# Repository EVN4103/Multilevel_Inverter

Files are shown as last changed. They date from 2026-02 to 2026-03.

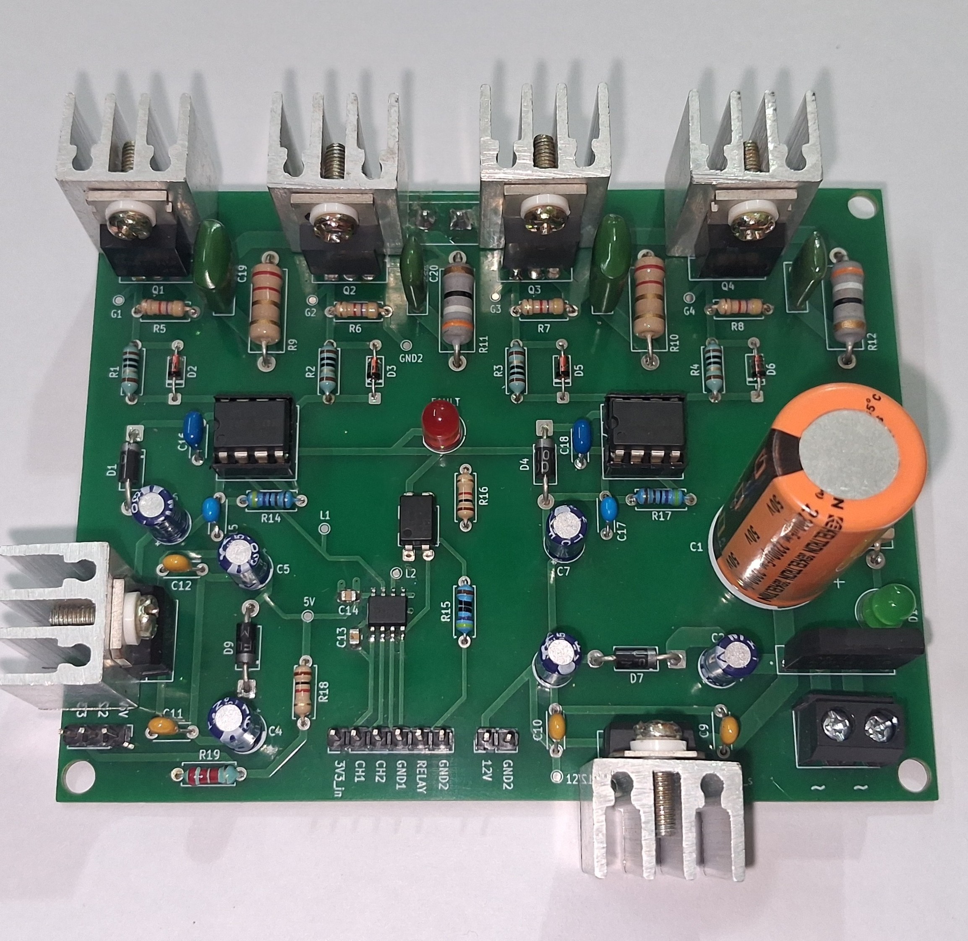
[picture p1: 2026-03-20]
hardware/hardware_setup/h-bridge.jpeg

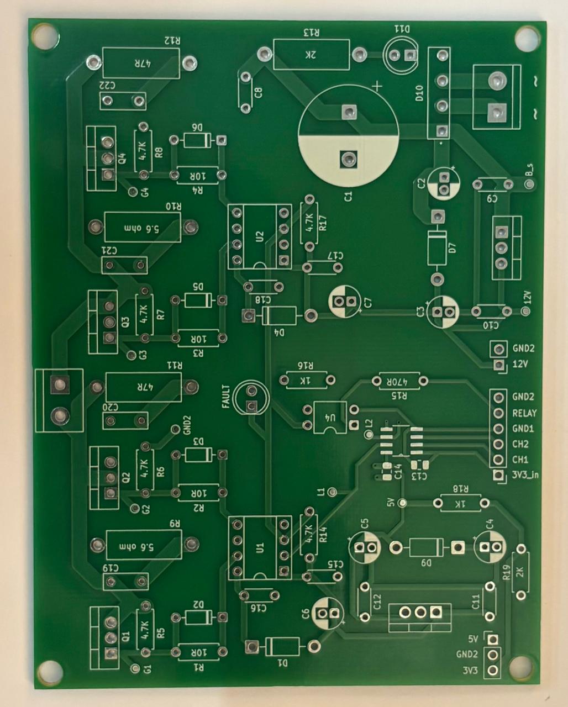
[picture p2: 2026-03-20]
hardware/hardware_setup/fabricated pcb .jpeg

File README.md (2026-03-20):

# 7-Level Cascaded H-Bridge Multilevel Inverter

A 7-Level Cascaded H-Bridge (CHB) Multilevel Inverter designed to generate high-quality AC output using Phase-Shifted Sinusoidal PWM (PS-SPWM) control implemented on an STM32F401 microcontroller.

# Project Overview

This project consists of:

- **Hardware**: Power stage and control PCB designed in KiCad  
- **Firmware**: STM32F401-based inverter control firmware  
- **Control Method**: Phase-Shifted Sinusoidal PWM (PS-SPWM)  
- **Target Applications**: Motor drives, renewable energy systems, medium-voltage inverter systems  

# Hardware

Designed using KiCad (EDA Suite)

# Hardware Features
- 3 Cascaded H-Bridge cells
- 7-level stepped AC output
- Modular and scalable architecture
- Designed for reduced harmonic distortion

# Firmware
Generated using STM32CubeMX  
Developed using STM32CubeIDE  

# Microcontroller
STM32F401CCU6

# Control Strategy
- Phase-Shifted Sinusoidal PWM (PS-SPWM)
- Configurable switching frequency
- Modular control structure

# Key Features

✔ Reduced Total Harmonic Distortion (THD)  
✔ Modular multilevel inverter topology  
✔ Timer-based PWM control  
✔ Scalable to higher voltage levels  
✔ Suitable for renewable and motor drive applications  
✔ Closed-loop voltage control implementation  
✔ FFT-based THD measurement
✔ Over-voltage, under-voltage, and over-current protection

# Prototype Setup
20260317_141503 jpg

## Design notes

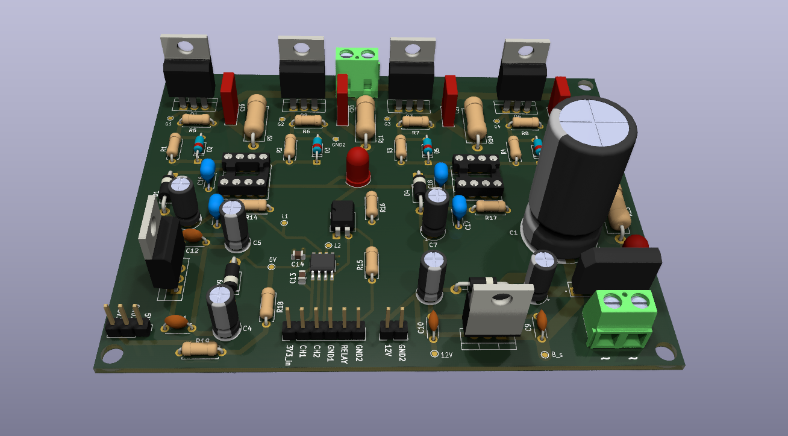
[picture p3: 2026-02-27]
hardware/hardware_design/pcb.png

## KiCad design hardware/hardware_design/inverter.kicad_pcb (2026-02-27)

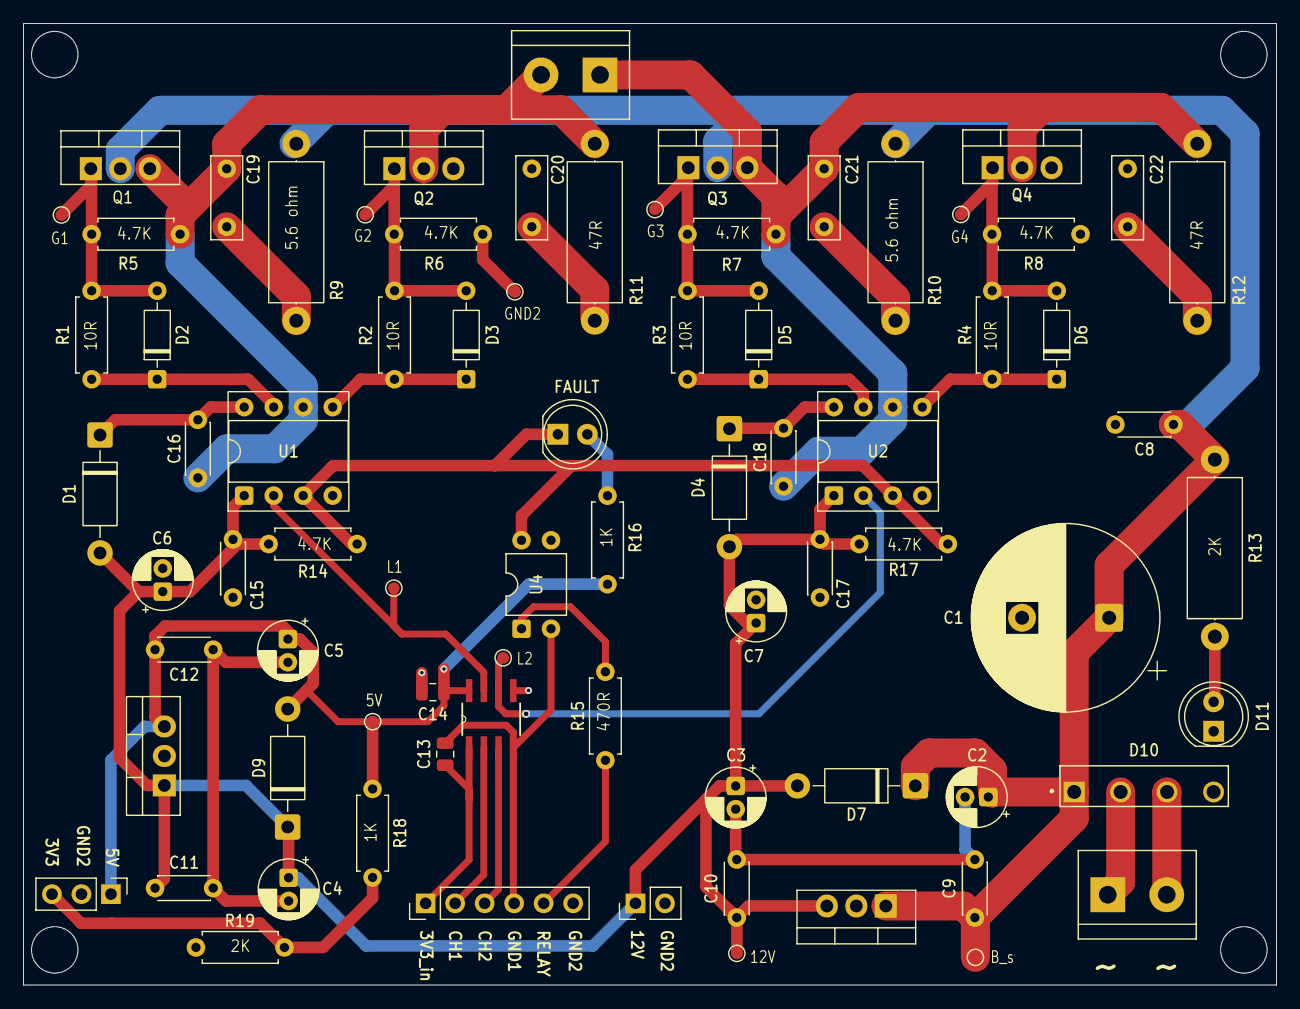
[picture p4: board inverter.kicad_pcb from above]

Board: 2 copper layers, 107.9 x 82.8 mm, 77 parts (0 on the bottom side), 36 nets.

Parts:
C1: 2200uF/50V; CP_Radial_D16.0mm_P7.50mm
C2, C4: 10uf; CP_Radial_D5.0mm_P2.00mm
C3, C5, C6: 10uF; CP_Radial_D5.0mm_P2.00mm
C7: 10uF e; CP_Radial_D5.0mm_P2.00mm
C8: 0.1uf; C_Disc_D4.3mm_W1.9mm_P5.00mm
C9, C11: 0.22uF; C_Disc_D4.3mm_W1.9mm_P5.00mm
C10, C12: 0.1uF; C_Disc_D4.3mm_W1.9mm_P5.00mm
C13, C14: 0.1uf; C_0805_2012Metric
C15, C17: 0.1uF,X7R; C_Disc_D4.3mm_W1.9mm_P5.00mm
C16, C18: 50V 1uF X7R; C_Disc_D4.3mm_W1.9mm_P5.00mm
C19, C21: 10nF; C_Rect_L7.0mm_W2.5mm_P5.00mm
C20, C22: 3.3nF; C_Rect_L7.0mm_W2.5mm_P5.00mm
D1, D4: SR1100; D_DO-41_SOD81_P10.16mm_Horizontal
D2, D3, D5, D6: 1N4448; D_DO-35_SOD27_P7.62mm_Horizontal
D7, D9: 1N5819; D_DO-41_SOD81_P10.16mm_Horizontal
D8: LED; LED_D5.0mm
D10: KBP208G; SIP350W80P400L1450H1280Q4
D11: LED_G; LED_D5.0mm
J1, J4: Screw_Terminal_01x02; TerminalBlock_bornier-2_P5.08mm
J2: Conn_01x06_Pin; PinHeader_1x06_P2.54mm_Vertical
J3: Conn_01x02_Pin; PinHeader_1x02_P2.54mm_Vertical
J5: Conn_01x03_Pin; PinHeader_1x03_P2.54mm_Vertical
Q1, Q2, Q3, Q4: IRF540N; TO-220-3_Vertical
R1, R2, R3, R4: 10R; R_Axial_DIN0207_L6.3mm_D2.5mm_P7.62mm_Horizontal
R5, R6, R7, R8, R14, R17: 4.7K; R_Axial_DIN0207_L6.3mm_D2.5mm_P7.62mm_Horizontal
R9, R10: 5.6 ohm, 1W; R_Axial_DIN0414_L11.9mm_D4.5mm_P15.24mm_Horizontal
R11, R12: 39 ohm, 1W; R_Axial_DIN0414_L11.9mm_D4.5mm_P15.24mm_Horizontal
R13: 2K; R_Axial_DIN0414_L11.9mm_D4.5mm_P15.24mm_Horizontal
R15: 470; R_Axial_DIN0207_L6.3mm_D2.5mm_P7.62mm_Horizontal
R16: 1K; R_Axial_DIN0207_L6.3mm_D2.5mm_P7.62mm_Horizontal
R18: 1k; R_Axial_DIN0207_L6.3mm_D2.5mm_P7.62mm_Horizontal
R19: 2k; R_Axial_DIN0207_L6.3mm_D2.5mm_P7.62mm_Horizontal
TP1: B_s; TestPoint_Pad_D1.0mm
TP2: 12V; TestPoint_Pad_D1.0mm
TP3: 5V; TestPoint_Pad_D1.0mm
TP4: CH1; TestPoint_Pad_D1.0mm
TP5: CH2; TestPoint_Pad_D1.0mm
TP6: S1; TestPoint_Pad_D1.0mm
TP7: S2; TestPoint_Pad_D1.0mm
TP8: S3; TestPoint_Pad_D1.0mm
TP9: S4; TestPoint_Pad_D1.0mm
TP10: GND2; TestPoint_Pad_D1.0mm
U1, U2: IR2104; DIP-8_W7.62mm_Socket
U3: ADUM1200BRZ-RL7; SOIC127P600X175-8N
U4: PC817; DIP-4_W7.62mm
U5: LM7805_TO220; TO-220-3_Vertical
U6: LM7812_TO220; TO-220-3_Vertical

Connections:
/3.3V MCU: C13.1, J2.1, U3.1 (VDD1)
/5V REG: C5.1, C12.1, C14.1, D9.2 (A), J5.1, R16.2, R18.1, TP3.1, U3.8 (VDD2), U5.3 (VO)
/12V_REG: C3.1, C4.1, C6.1, C7.1, C10.1, C11.1, C15.1, C17.1, D1.2 (A), D4.2 (A), D7.2 (A), D9.1 (K), J3.1, R14.2, R17.2, TP2.1, U1.1 (VCC), U2.1 (VCC), U5.1 (VI), U6.3 (VO)
/AC1: D10.3, J1.2
/AC2: D10.2, J1.1
/BRIDGE+DRIVER/gate_1: D2.2 (A), Q1.1 (G), R1.2, R5.2, TP6.1
/BRIDGE+DRIVER/gate_2: D3.2 (A), Q2.1 (G), R2.2, R6.2, TP7.1
/BRIDGE+DRIVER/gate_3: D5.2 (A), Q3.1 (G), R3.2, R7.2, TP8.1
/BRIDGE+DRIVER/gate_4: D6.2 (A), Q4.1 (G), R4.2, R8.2, TP9.1
/BRIDGE+DRIVER/node_1: C16.2, C19.2, J4.2, Q1.3 (S), Q2.2 (D), R5.1, R11.1, U1.6 (VS)
/BRIDGE+DRIVER/node_2: C18.2, C21.2, J4.1, Q3.3 (S), Q4.2 (D), R7.1, R12.1, U2.6 (VS)
/Bridge_supply: C1.1, C2.1, C8.1, C9.1, D7.1 (K), D10.1, Q1.2 (D), Q3.2 (D), R9.1, R10.1, R13.1, TP1.1, U6.1 (VI)
/Leg_1_in: J2.2, U3.2 (VIA)
/Leg_1_out: TP4.1, U1.2 (IN), U3.7 (VOA)
/Leg_2_in: J2.3, U3.3 (VIB)
/Leg_2_out: TP5.1, U2.2 (IN), U3.6 (VOB)
/SD_in: D8.1 (K), R14.1, R17.1, U1.3 (~SD), U2.3 (~SD), U4.4
/relay_sig_in: J2.5, R15.1
GND1: C13.2, J2.4, U3.4 (GND1), U4.2
GND2: C1.2, C6.2, C7.2, C8.2, C14.2, C15.2, C17.2, C20.2, C22.2, D10.4, D11.1 (K), J2.6, J3.2, J5.2, Q2.3 (S), Q4.3 (S), R6.1, R8.1, R19.2, TP10.1, U1.4 (COM), U2.4 (COM), U3.5 (GND2), U4.3, U5.2 (GND), U6.2 (GND)
unnamed: C2.2, C3.2, C9.2, C10.2
unnamed: C4.2, C5.2, C11.2, C12.2
unnamed: C19.1, R9.2
unnamed: C20.1, R11.2
unnamed: C21.1, R10.2
unnamed: C22.1, R12.2
unnamed: C16.1, D1.1 (K), U1.8 (VB)
unnamed: D2.1 (K), R1.1, U1.7 (HO)
unnamed: D3.1 (K), R2.1, U1.5 (LO)
unnamed: C18.1, D4.1 (K), U2.8 (VB)
unnamed: D5.1 (K), R3.1, U2.7 (HO)
unnamed: D6.1 (K), R4.1, U2.5 (LO)
unnamed: D8.2 (A), R16.1
unnamed: D11.2 (A), R13.2
unnamed: J5.3, R18.2, R19.1
unnamed: R15.2, U4.1

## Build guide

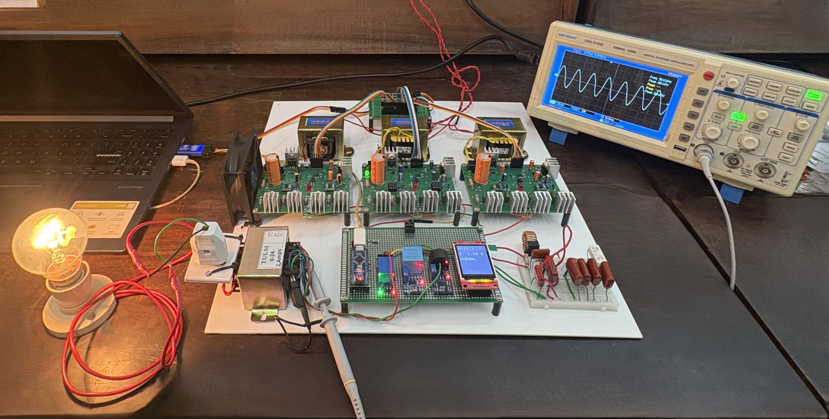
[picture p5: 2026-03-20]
hardware/hardware_setup/exp_setup.jpg

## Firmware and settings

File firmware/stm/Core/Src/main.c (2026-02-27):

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
/* Includes ------------------------------------------------------------------*/
#include "main.h"

/* USER CODE BEGIN Includes */
#include "ssd1306.h"
#include "ssd1306_fonts.h"
#include "arm_math.h"

#include <math.h>
#include <stdint.h>
#include <stdio.h>
#include <string.h>


/* ========== NTC CONFIG ========== */
#define ADC_MAX             4095.0f
#define SERIES_RESISTOR     10000.0f
#define NTC_NOMINAL         10000.0f
#define TEMP_NOMINAL        25.0f
#define BETA_COEFFICIENT    3950.0f

#define TEMP_WARNING        70.0f
#define TEMP_SHUTDOWN       85.0f

#define ADC_SAMPLES         8
/* ========== NTC CONFIG ========== */


#define ARR         999   // Timer period
#define SAMPLES     480    // Number of samples per sine wave



uint16_t CCR_table_A[SAMPLES];  // S1/S2/S5/S6/S9/S10
uint16_t CCR_table_B[SAMPLES];  // S3/S4/S7/S8/S11/S12



void generate_sine_table(void)
{
    for(int i = 0; i < SAMPLES; i++)
    {
        float angle    = 2.0f * 3.14159265358979323846f * i / SAMPLES;
        float sine_val = (sinf(angle) + 1.0f) * 0.5f;
        uint16_t duty  = (uint16_t)(sine_val * ARR + 0.5f);


        CCR_table_A[i] = duty;                           // LEG-A/C/E
        CCR_table_B[i] = (uint16_t)(ARR - duty);		 // LEG-B/D/F
    }
}
/* USER CODE END Includes */

I2C_HandleTypeDef hi2c1;

TIM_HandleTypeDef htim1;
TIM_HandleTypeDef htim3;
TIM_HandleTypeDef htim4;
DMA_HandleTypeDef hdma_tim1_ch1;
DMA_HandleTypeDef hdma_tim1_ch2;
DMA_HandleTypeDef hdma_tim3_ch1_trig;
DMA_HandleTypeDef hdma_tim3_ch3;
DMA_HandleTypeDef hdma_tim4_ch1;
DMA_HandleTypeDef hdma_tim4_ch2;

UART_HandleTypeDef huart2;

/* USER CODE BEGIN PV */
uint8_t rx_byte;
char uart_buffer[50];
int uart_index = 0;




void start_synchronized_pwms(void)
{
	// 1️⃣ Start DMA PWM (but don't start counters yet)

	//BRIDGE-1
	HAL_TIM_PWM_Start_DMA(&htim1, TIM_CHANNEL_1, (uint32_t*)CCR_table_A, SAMPLES); // LEG-A
	HAL_TIM_PWM_Start_DMA(&htim1, TIM_CHANNEL_2, (uint32_t*)CCR_table_B, SAMPLES); // LEG-B


	//BRIDGE-2
	HAL_TIM_PWM_Start_DMA(&htim3, TIM_CHANNEL_1, (uint32_t*)CCR_table_A, SAMPLES); // LEG-C
	HAL_TIM_PWM_Start_DMA(&htim3, TIM_CHANNEL_3, (uint32_t*)CCR_table_B, SAMPLES); // LEG-D


	//BRIDGE-3
	HAL_TIM_PWM_Start_DMA(&htim4, TIM_CHANNEL_1, (uint32_t*)CCR_table_A, SAMPLES); // LEG-E
	HAL_TIM_PWM_Start_DMA(&htim4, TIM_CHANNEL_2, (uint32_t*)CCR_table_B, SAMPLES); // LEG-F







	// 2️⃣ Set initial counter offsets (phase shift)
	__HAL_TIM_SET_COUNTER(&htim1, 0);     // 0°   --- bridge1--S1/S2/S3/S4
	__HAL_TIM_SET_COUNTER(&htim3, ARR/6); // 60°  --- bridge2--S5/S6/S7/S8
	__HAL_TIM_SET_COUNTER(&htim4, ARR/3); // 120° --- bridge3--S9/S10/S11/S12



	// 3️⃣ Start ALL timers AT ONCE
	HAL_TIM_Base_Start(&htim1);	//BRIDGE-1
	HAL_TIM_Base_Start(&htim3);	//BRIDGE-2
	HAL_TIM_Base_Start(&htim4); //BRIDGE-3

}
/* USER CODE END PV */

void SystemClock_Config(void);
static void MX_GPIO_Init(void);
static void MX_DMA_Init(void);
static void MX_TIM1_Init(void);
static void MX_TIM3_Init(void);
static void MX_TIM4_Init(void);
static void MX_I2C1_Init(void);
static void MX_USART2_UART_Init(void);
/**
  * @brief  The application entry point.
  * @retval int
  */
int main(void)
{

  /* MCU Configuration--------------------------------------------------------*/

  /* Reset of all peripherals, Initializes the Flash interface and the Systick. */
  HAL_Init();

  /* Configure the system clock */
  SystemClock_Config();

  /* Initialize all configured peripherals */
  MX_GPIO_Init();
  MX_DMA_Init();
  MX_TIM1_Init();
  MX_TIM3_Init();
  MX_TIM4_Init();
  MX_I2C1_Init();
  MX_USART2_UART_Init();
  /* USER CODE BEGIN 2 */
  	generate_sine_table();         // Fill all 6 tables with SAME sine
    start_synchronized_pwms();     // Start DMA + timers with carrier shift

    ssd1306_Init();       // start OLED
    ssd1306_Fill(Black);
    ssd1306_UpdateScreen();

    // Start UART interrupt receive
    HAL_UART_Receive_IT(&huart2, &rx_byte, 1);
  /* USER CODE END 2 */

  /* Infinite loop */
  /* USER CODE BEGIN WHILE */
  while (1)
  {
    /* USER CODE END WHILE */

    /* USER CODE BEGIN 3 */
  }
  /* USER CODE END 3 */
}

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
/* USER CODE BEGIN 4 */
void HAL_UART_RxCpltCallback(UART_HandleTypeDef *huart)
{
    if(huart->Instance == USART2)
    {
        // store incoming characters
        if(rx_byte != '\n' && uart_index < 49)
        {
            uart_buffer[uart_index++] = rx_byte;
        }
        else
        {
            uart_buffer[uart_index] = '\0';   // complete string
            uart_index = 0;

            // 🔥 DISPLAY ON OLED
            ssd1306_Fill(Black);

            ssd1306_SetCursor(0,0);
            ssd1306_WriteString("UART Data:", Font_7x10, White);

            ssd1306_SetCursor(0,20);
            ssd1306_WriteString(uart_buffer, Font_7x10, White);

            ssd1306_UpdateScreen();
        }

        HAL_UART_Receive_IT(&huart2, &rx_byte, 1);
    }
}
/* USER CODE END 4 */
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


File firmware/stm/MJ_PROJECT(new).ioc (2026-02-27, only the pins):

Mcu.UserName=STM32F401CCUx
PA2.Signal=USART2_TX
PA3.Signal=USART2_RX
PA6.Signal=S_TIM3_CH1
PA8.Signal=S_TIM1_CH1
PA9.Signal=S_TIM1_CH2
PB0.Signal=S_TIM3_CH3
PB6.Signal=S_TIM4_CH1
PB7.Signal=S_TIM4_CH2
PB8.Signal=I2C1_SCL
PB9.Signal=I2C1_SDA

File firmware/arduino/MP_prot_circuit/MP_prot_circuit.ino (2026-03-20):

#include <TFT.h>
#include <SPI.h>
#include <math.h>

// ---- function declarations (fix compile error) ----
float calibrateCurrentOffset();
float measureCurrent();
String prevStatus = "";

#define cs 10
#define dc 9
#define rst 8

#define VOLTAGE_PIN A7
#define CURRENT_PIN A5
#define RELAY_PIN 4
#define RESET_BTN 6
#define FAULT_PIN 7

// -------- Protection Limits --------
#define OVER_CURRENT 4.0
#define UNDER_VOLTAGE 10.0
#define OVER_VOLTAGE 85.0

TFT TFTscreen = TFT(cs, dc, rst);

// -------- Voltage ----------
float voltage;
float prevVoltage = -1;
float v_calibration = 555.0;

// -------- Current ----------
const float currentCalibration = 0.01700;
const int sampleCount = 1000;
float currentOffset;
float current;
float prevCurrent = -1;

// -------- Status ----------
bool faultActive = false;
bool systemTripped = false;
String faultMessage = "NORMAL";


// ================= SETUP =================
void setup()
{

  pinMode(FAULT_PIN, OUTPUT);
  digitalWrite(FAULT_PIN, LOW);   // no fault initially

  pinMode(RELAY_PIN, OUTPUT);
  digitalWrite(RELAY_PIN, LOW); // relay ON (active LOW)

  pinMode(RESET_BTN, INPUT_PULLUP);

  Serial.begin(115200);

  TFTscreen.begin();
  TFTscreen.setRotation(0);
  TFTscreen.background(0, 0, 0);
  TFTscreen.setTextSize(2);

  TFTscreen.stroke(0,255,0);
  TFTscreen.text("V:", 5, 10);

  TFTscreen.stroke(0,255,255);
  TFTscreen.text("I:", 5, 40);

  currentOffset = calibrateCurrentOffset();
}


// ================= LOOP =================
void loop()
{
  // ===== RESET BUTTON =====
  if(digitalRead(RESET_BTN)==LOW)
  {
    delay(60);
    if(digitalRead(RESET_BTN)==LOW)
    {
      systemTripped = false;
      faultMessage = "RESET OK";
      digitalWrite(RELAY_PIN, LOW);
    }
  }

  // -------- VOLTAGE RMS --------
  long sum = 0;
  int samples = 500;
  long offset = 0;

  for(int i=0;i<200;i++)
  {
    offset += analogRead(VOLTAGE_PIN);
    delayMicroseconds(200);
  }

  offset = offset/200;

  for (int i = 0; i < samples; i++)
  {
    int val = analogRead(VOLTAGE_PIN) - offset;
    sum += (long)val * val;
    delayMicroseconds(200);
  }

  float mean = sum / (float)samples;
  float rms = sqrt(mean);

  float sensorVoltage = rms * (5.0 / 1023.0);
  float rawVoltage = sensorVoltage * v_calibration;

  static float smoothVoltage = 0;
  smoothVoltage = (smoothVoltage * 0.4) + (rawVoltage * 0.4);

  voltage = smoothVoltage;

  // -------- CURRENT RMS --------
  current = measureCurrent();

  Serial.print("V:");
  Serial.print(voltage);
  Serial.print(" I:");
  Serial.println(current,3);

  // ===== PROTECTION =====
  faultActive = false;

  if(!systemTripped)
    faultMessage = "NORMAL";

  if (current > OVER_CURRENT)
  {
    faultActive = true;
    faultMessage = "OVER CURRENT";
  }

  if (voltage < UNDER_VOLTAGE)
  {
    faultActive = true;
    faultMessage = "UNDER VOLT";
  }

  if (voltage > OVER_VOLTAGE)
  {
    faultActive = true;
    faultMessage = "OVER VOLT";
  }

  if(faultActive)
  {
    systemTripped = true;
  }

  // relay control
  if(systemTripped)
{
    digitalWrite(RELAY_PIN, HIGH); // relay OFF
    digitalWrite(FAULT_PIN, HIGH); // FAULT SIGNAL
}
  else
{
    digitalWrite(RELAY_PIN, LOW);  // relay ON
    digitalWrite(FAULT_PIN, LOW);  // NORMAL
}

  // ===== TFT VOLTAGE =====
  if (abs(voltage - prevVoltage) > 0.5)
  {
    TFTscreen.stroke(0,0,0);

    char oldV[10];
    dtostrf(prevVoltage, 4, 1, oldV);
    TFTscreen.text(oldV, 30, 10);

    TFTscreen.stroke(255,255,0);

    char newV[10];
    dtostrf(voltage, 4, 1, newV);
    TFTscreen.text(newV, 30, 10);
    TFTscreen.text("V", 100, 10);

    prevVoltage = voltage;
  }

  // ===== TFT CURRENT =====
  if (abs(current - prevCurrent) > 0.02)
  {
    TFTscreen.stroke(0,0,0);

    char oldC[10];
    dtostrf(prevCurrent, 4, 2, oldC);
    TFTscreen.text(oldC, 40, 40);

    TFTscreen.stroke(0,255,255);

    char newC[10];
    dtostrf(current, 4, 2, newC);
    TFTscreen.text(newC, 40, 40);
    TFTscreen.text("A", 100, 40);

    prevCurrent = current;
  }

  // ===== TFT STATUS =====
String currentStatus;

if(systemTripped)
  currentStatus = faultMessage;
else
  currentStatus = "NORMAL";

if(currentStatus != prevStatus)
{
  // clear status area
  TFTscreen.fillRect(0, 70, 160, 20, 0);

  if(systemTripped)
    TFTscreen.stroke(255,0,0);
  else
    TFTscreen.stroke(0,255,0);

  TFTscreen.text(currentStatus.c_str(),5,70);

  prevStatus = currentStatus;
}

  delay(200);
}


// ================= CURRENT FUNCTIONS =================
float calibrateCurrentOffset()
{
  long total = 0;

  for (int i = 0; i < 500; i++)
  {
    total += analogRead(CURRENT_PIN);
  }

  return total / (float)500;
}


float measureCurrent()
{
  long total = 0;

  currentOffset = calibrateCurrentOffset();

  for (int i = 0; i < sampleCount; i++)
  {
    float v = analogRead(CURRENT_PIN) - currentOffset;
    total += v * v;
  }

  float rms = sqrt(total / (float)sampleCount);
  float amp = rms * currentCalibration;

  if (amp < 0.01)
    amp = 0;

  return amp;
}

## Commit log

2026-02-27 Initial commit - Added hardware and firmware files
    [74HC02N.step, Major_Project.kicad_pcb, inverter.kicad_pcb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]
2026-02-27 PCB view updated
2026-02-27 Added PCB layout image
2026-03-20 prototype image updated
2026-03-20 Hardware setup and hardware design updated
    [74HC02N.step, Major_Project.kicad_pcb, inverter.kicad_pcb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]
2026-03-20 Arduino and STM firmware updated
2026-04-04 Updated inverter schematic
    [inverter.kicad_sch, untitled.kicad_sch]

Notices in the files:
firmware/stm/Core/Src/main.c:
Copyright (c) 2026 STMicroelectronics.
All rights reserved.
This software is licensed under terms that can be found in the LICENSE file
